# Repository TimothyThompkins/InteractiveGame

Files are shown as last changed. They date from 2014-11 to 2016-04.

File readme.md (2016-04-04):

## Description

This is a work in progress, but ultimately aspires to a space invaders-esque game which is played completely on an embedded touch controller and interfaced with a display device such as a computer, or Rasbery Pi.

### Current revision of the PCB:

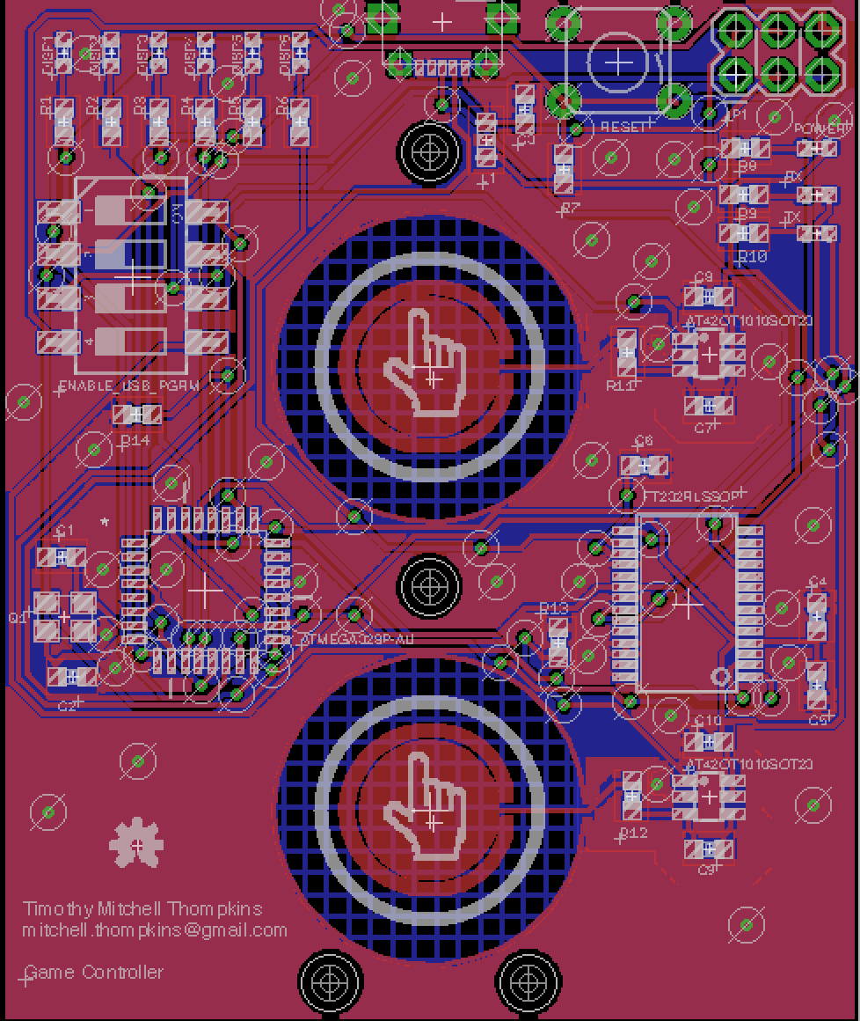
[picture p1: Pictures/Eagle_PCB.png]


### The unpopulated (left) and populated (right) boards:

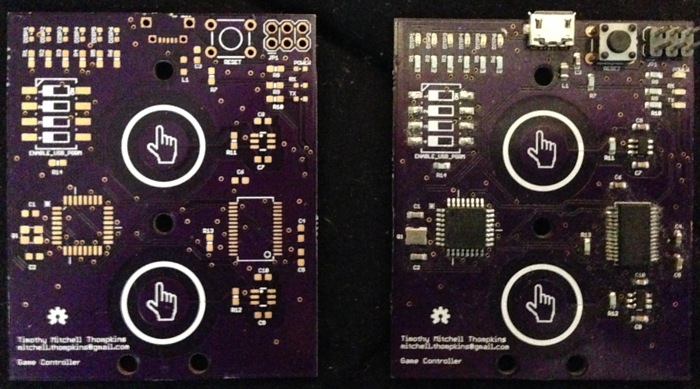
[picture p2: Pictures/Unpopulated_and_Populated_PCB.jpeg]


### Loading screen for the game, developed in python:

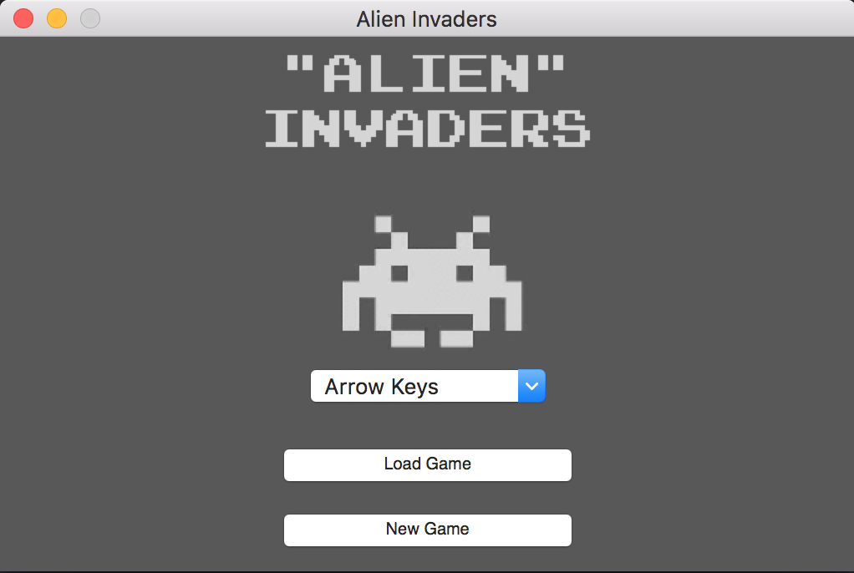
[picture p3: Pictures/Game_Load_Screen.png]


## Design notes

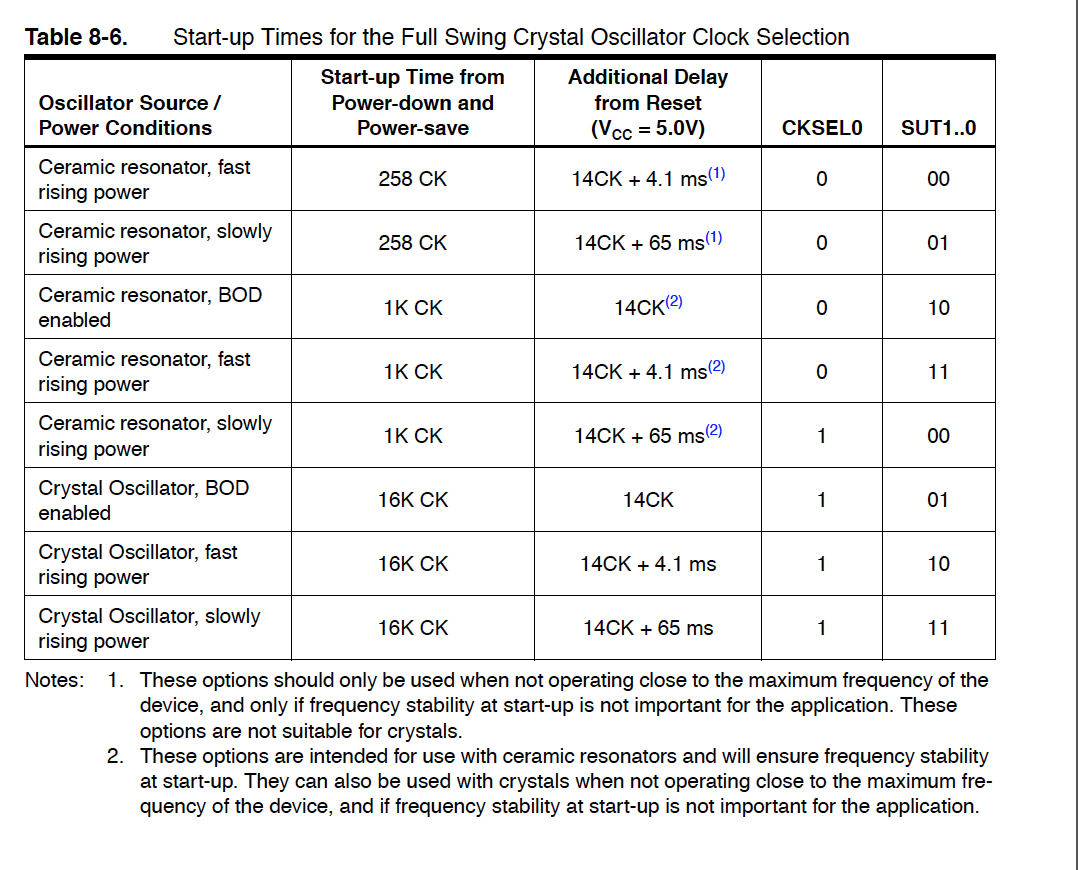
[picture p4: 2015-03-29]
Fuse Settings/High Fuse bit settings 2.png

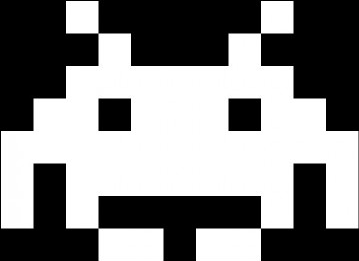
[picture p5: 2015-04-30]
Game/python/characters/alien.gif

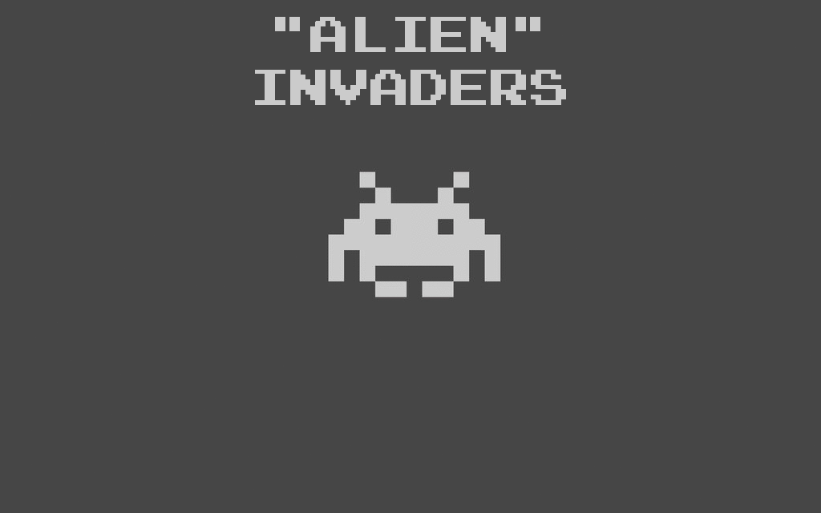
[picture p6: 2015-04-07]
Game/python/Space_Invaders_Background_Image.gif

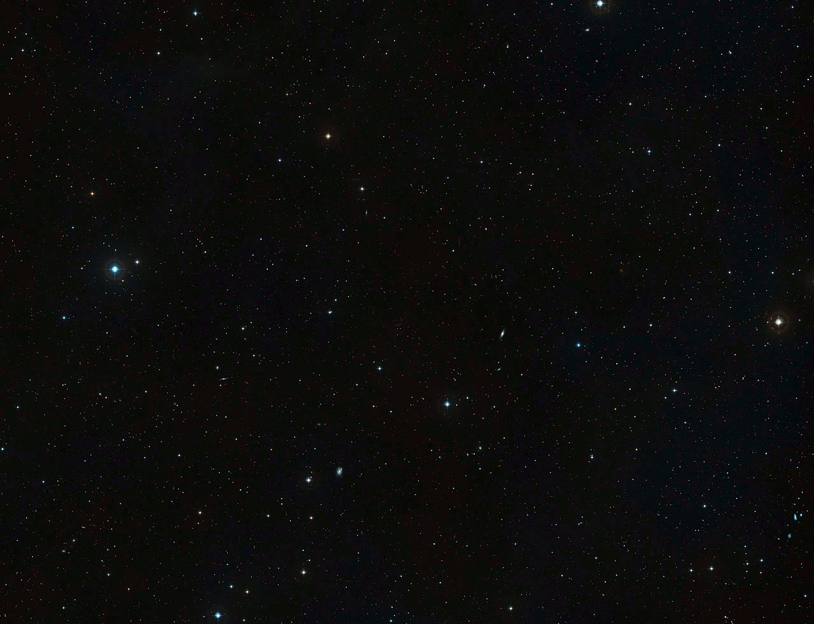
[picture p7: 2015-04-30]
Game/python/Game_Background.gif

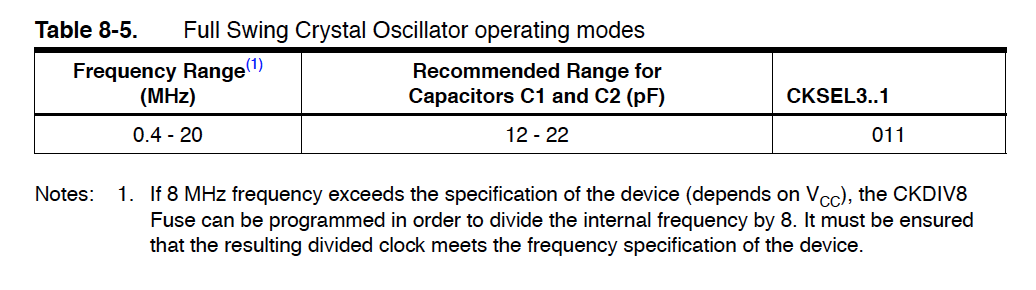
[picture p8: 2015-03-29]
Fuse Settings/High Fuse bit settings 1.png

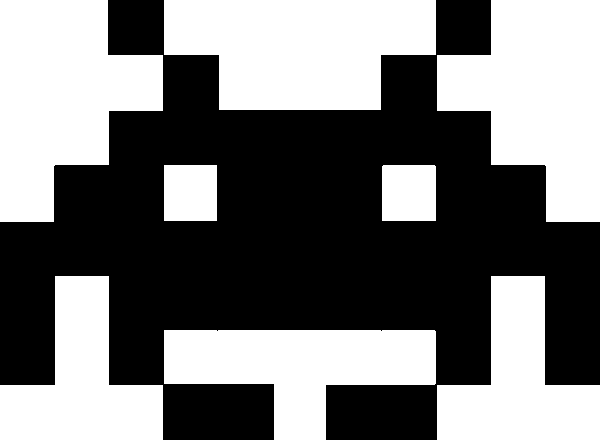
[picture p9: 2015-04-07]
Game/python/characters/temp.gif

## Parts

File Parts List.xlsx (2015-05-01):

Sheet: Parts List
 | Part | Package/Mounting Type | Size | Quantity | Notes | Order Link
Capacitors | 10 pF | SMD | 0603 | 2 | For Oscillator | http://www.digikey.com/product-detail/en/CL10C100JB8NCNC/1276-2154-1-ND/3890240
 | .01 μF | SMD | 0603 | 1 |  | http://www.digikey.com/product-detail/en/C0603C103K5RACTU/399-1091-1-ND/411366
 | .1 μF | SMD | 0603 | 14 |  | http://www.digikey.com/product-detail/en/CC0603KRX7R9BB104/311-1344-1-ND/2103128
 | 4.7 μF | SMD | 0603 | 2 |  | http://www.digikey.com/product-detail/en/CL10A475KA8NQNC/1276-1900-1-ND/3889986
Resistors | 150 Ω | SMD | 0603 | 9 |  | http://www.digikey.com/product-detail/en/MCT06030C1500FP500/MCT0603-150-CFCT-ND/2607884
 | 330 Ω | SMD | 0603 | 6 |  | http://www.digikey.com/product-detail/en/ESR03EZPJ331/RHM330DCT-ND/1762933
 | 10 kΩ | SMD | 0603 | 1 |  | http://www.digikey.com/product-detail/en/MCT06030C1002FP500/MCT0603-10.0K-CFCT-ND/2607933
LED | Red | SMD | 0603 | 6 | 1/8W 150 Ω Resistor | http://www.digikey.com/product-detail/en/APT1608SRCPRV/754-1122-1-ND/1747839
 | Yellow | SMD | 0603 | 1 | 1/8W 150 Ω Resistor | http://www.digikey.com/product-detail/en/APT1608SYCK/754-1124-1-ND/1747841
 | Green | SMD | 0603 | 2 | 1/8W 150 Ω Resistor | http://www.digikey.com/product-detail/en/APT1608CGCK/754-1116-1-ND/1747833
Bead | BK2125HS470-T | SMD | 0805 | 1 |  | http://www.digikey.com/product-detail/en/BK2125HS470-T/587-1911-1-ND/1465381
Chips | AT42QT1010SOT23 | SOT23-6 | N/A | 4 |  | http://www.digikey.com/product-detail/en/AT42QT1010-TSHR/AT42QT1010-TSHRCT-ND/2268871
 | ATMEGA328P | TQFP-32 | N/A | 1 |  | http://www.digikey.com/product-detail/en/ATMEGA328P-AU/ATMEGA328P-AU-ND/1832260
 | FT232RL | SSOP28DB | N/A | 1 |  | http://www.digikey.com/product-detail/en/FT232RL-REEL/768-1007-1-ND/1836402
Comms | FCI Micro-B USB | SMD/Through-Hole | N/A | 1 |  | http://www.digikey.com/product-detail/en/10118194-0001LF/609-4618-1-ND/2785382
Jumpers | 3x2 | Through-Hole | 2.54mm | 1 |  | http://www.digikey.com/product-detail/en/M20-9980346/952-2121-ND/3728085
Buttons | Momentary Push-Button | Through-Hole |  | 1 |  | N/A
Oscillator | 20 MHz Crystal Oscillator | SMD | 3.2mmx2.5mm | 1 | Assume Cstray = 4pF | http://www.digikey.com/product-detail/en/TSX-3225%2020.0000MF20G-AC3/SER3629CT-ND/1802880
 | MIC5205 | SOT23-5 |  | 1 |  | http://www.digikey.com/product-detail/en/MIC5205-3.3YM5%20TR/576-1259-1-ND/771886

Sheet: LED Calculations
Required Values of R given Vf, Vcc, and Current Max |  |  |  |  |  |  | How Changing R will affect I and P given Vf
Current Max | Vcc | Vf | R | P (V*I) | P (I2R) | Color | Vf (Given by Datasheet) | Choose R | I ((Vcc-Vf)/R) | P (I2R)
0.02 | 5 | 1.5 | 175 | 0.07 | 0.07 | Red | 1.85 | 150 | 0.021 | 0.06615
 |  | 1.6 | 170 | 0.068 | 0.068 | Yellow | 2 | 150 | 0.02 | 0.06
 |  | 1.7 | 165 | 0.066 | 0.066 | Green | 2.1 | 150 | 0.01933333333 | 0.05606666667
 |  | 1.8 | 160 | 0.064 | 0.064
 |  | 1.9 | 155 | 0.062 | 0.062 | NOTE: These LED's have a test current of 20mA and no series resistor is greater than 1/8 W (.125 W)
 |  | 2 | 150 | 0.06 | 0.06
 |  | 2.1 | 145 | 0.058 | 0.058
 |  | 2.2 | 140 | 0.056 | 0.056
 |  | 2.3 | 135 | 0.054 | 0.054
 |  | 2.4 | 130 | 0.052 | 0.052
 |  | 2.5 | 125 | 0.05 | 0.05
 |  | 2.6 | 120 | 0.048 | 0.048
 |  | 1.85 | 157.5 | 0.063 | 0.063

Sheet: Oscillator Calculations
Calculations for C1/C2
CL is given by datasheet and Cstray is assumed (usually between 2-5 pF) |  | Checking CL
CL (pF) | 9 | CL (pF) | 9
Cstray (pF) | 4 | C1 (pF) | 10
Calculated C1 and C2 (pF) | 10 | C2 (pF) | 10

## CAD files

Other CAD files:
Sketchup Files/Controller_Board.skp

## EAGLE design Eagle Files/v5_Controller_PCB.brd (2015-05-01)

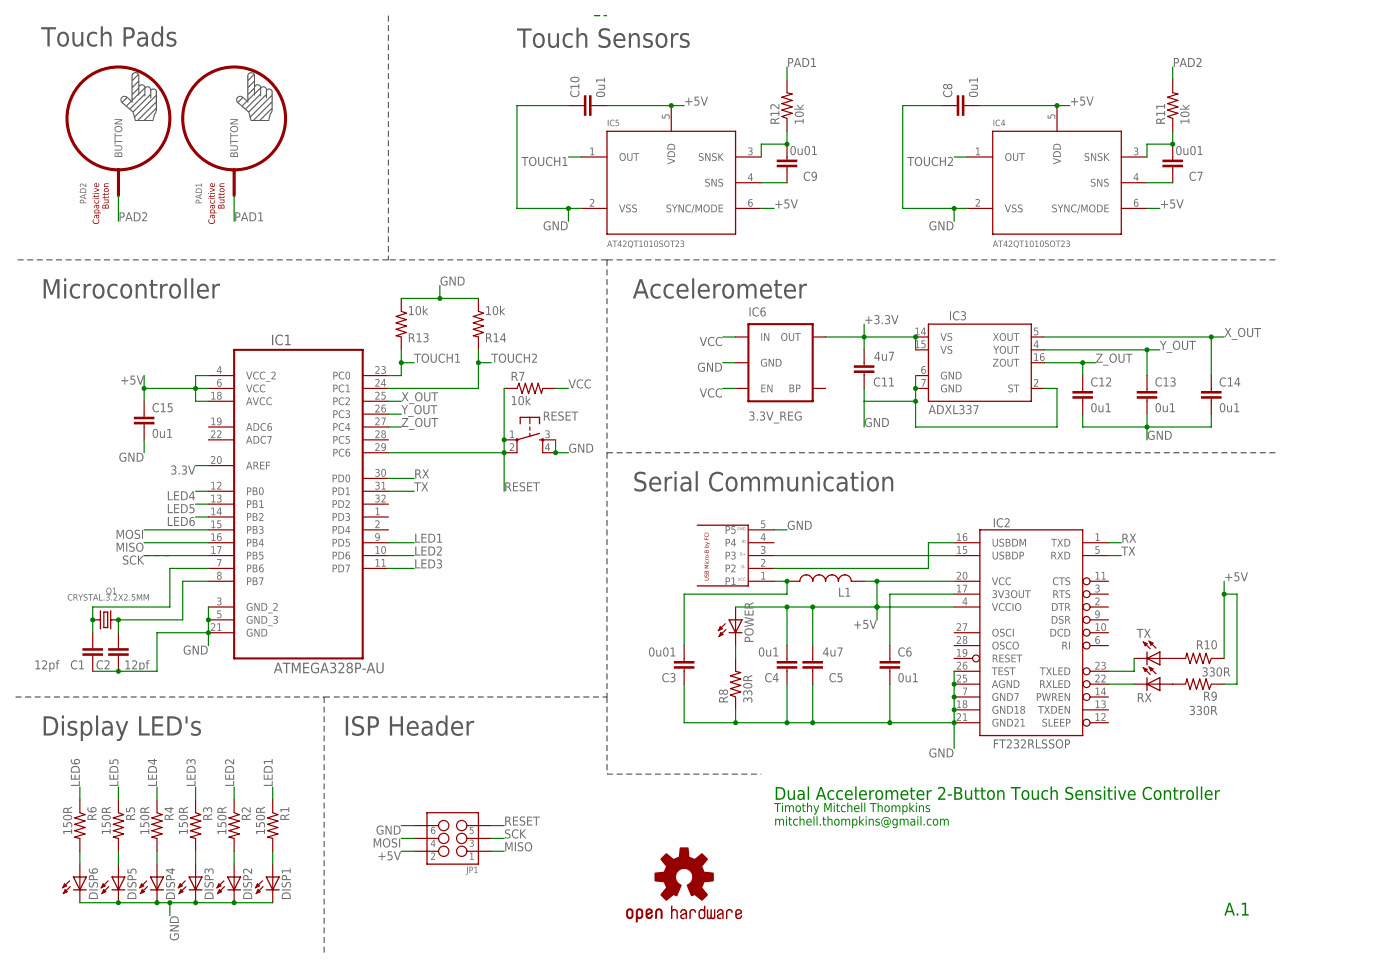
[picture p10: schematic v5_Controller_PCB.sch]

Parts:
BUTTON1: TOUCH_LOGO
C1, C2: 12pf; C0603
C3, C7, C9: 0u01; C0603
C4, C6, C8, C10, C12, C13, C14, C15: 0u1; C0603
C5, C11: 4u7; C0603
DISP1, DISP2, DISP3, DISP4, DISP5, DISP6: LEDCHIPLED_0603; CHIPLED_0603
IC1: ATMEGA328P-AU; QFP80P900X900X120-32N
IC2: FT232RLSSOP; SSOP28DB
IC3: ADXL337; LFCSP_LQ-16
IC4, IC5: AT42QT1010SOT23; SOT23-6
IC6: 3.3V_REG; SOT23-5
JP1: M03X2POGO_PINS; 2X3_POGO
L1: L-USL2012C; L2012C
LOGO2: OSHW-LOGOS; OSHW-LOGO-S
PAD1, PAD2: BUTTON_PASSIVE8MM; BUTTON_PASSIVE_8MM
POWER: LEDCHIPLED_0603; CHIPLED_0603
Q1: CRYSTAL.3.2X2.5MM; 3.2X2.5MM
R1, R2, R3, R4, R5, R6: 150R; 0603-RES
R7, R11, R12, R13, R14: 10k; 0603-RES
R8, R9, R10: 330R; 0603-RES
RESET: RESET; TACTILE_SWITCH_SMD
RX: LEDCHIPLED_0603; CHIPLED_0603
TX: LEDCHIPLED_0603; CHIPLED_0603
U$1: USB_MICRO_B_FCI; 10118194-0001LF
U$6: TOUCH_LOGO

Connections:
3.3V: IC1.20 (AREF)
+3.3V: C11.2, IC3.14 (VS), IC3.15 (VS), IC6.5 (OUT)
+5V: C4.2, C5.2, C8.2, C10.2, C15.1, IC1.4 (VCC_2), IC1.6 (VCC), IC1.18 (AVCC), IC2.4 (VCCIO), IC2.20 (VCC), IC4.5 (VDD), IC4.6 (SYNC/MODE), IC5.5 (VDD), IC5.6 (SYNC/MODE), JP1.P$2 (2), L1.2, POWER.A, R9.1, R10.1
GND: C1.1, C2.1, C3.1, C4.1, C5.1, C6.2, C8.1, C10.1, C11.1, C15.2, DISP1.C, DISP2.C, DISP3.C, DISP4.C, DISP5.C, DISP6.C, IC1.3 (GND_2), IC1.5 (GND_3), IC1.21 (GND), IC2.7 (GND7), IC2.18 (GND18), IC2.21 (GND21), IC2.25 (AGND), IC2.26 (TEST), IC3.2 (ST), IC3.6 (GND), IC3.7 (GND), IC4.2 (VSS), IC5.2 (VSS), IC6.2 (GND), JP1.P$6 (6), Q1.2 (GND), Q1.4 (GND), R8.1, R13.1, R14.1, RESET.3, RESET.4, U$1.5, U$1.GND@1 (GND), U$1.GND@2 (GND), U$1.GND@3 (GND), U$1.GND@4 (GND)
LED1: IC1.9 (PD5), R1.1
LED2: IC1.10 (PD6), R2.1
LED3: IC1.11 (PD7), R3.1
LED4: IC1.12 (PB0), R4.1
LED5: IC1.13 (PB1), R5.1
LED6: IC1.14 (PB2), R6.1
MISO: IC1.16 (PB4), JP1.P$1 (1)
MOSI: IC1.15 (PB3), JP1.P$4 (4)
unnamed: C9.2, IC5.3 (SNSK), R12.1
unnamed: C3.2, L1.1, U$1.1
unnamed: C2.2, IC1.8 (PB7), Q1.3
unnamed: C9.1, IC5.4 (SNS)
unnamed: POWER.C, R8.2
unnamed: C1.2, IC1.7 (PB6), Q1.1
unnamed: R10.2, TX.A
unnamed: C6.1, IC2.17 (3V3OUT)
unnamed: R9.2, RX.A
unnamed: IC2.16 (USBDM), U$1.2
unnamed: IC2.15 (USBDP), U$1.3
unnamed: IC2.23 (TXLED), TX.C
unnamed: IC2.22 (RXLED), RX.C
unnamed: C12.2, C13.2, C14.2
unnamed: C7.1, IC4.4 (SNS)
unnamed: C7.2, IC4.3 (SNSK), R11.1
unnamed: DISP1.A, R1.2
unnamed: DISP2.A, R2.2
unnamed: DISP3.A, R3.2
unnamed: DISP4.A, R4.2
unnamed: DISP5.A, R5.2
unnamed: DISP6.A, R6.2
PAD1: PAD1.P$1, R12.2
PAD2: PAD2.P$1, R11.2
RESET: IC1.29 (PC6), JP1.P$5 (5), R7.1, RESET.1, RESET.2
RX: IC1.30 (PD0), IC2.1 (TXD)
SCK: IC1.17 (PB5), JP1.P$3 (3)
TOUCH1: IC1.23 (PC0), IC5.1 (OUT), R13.2
TOUCH2: IC1.24 (PC1), IC4.1 (OUT), R14.2
TX: IC1.31 (PD1), IC2.5 (RXD)
VCC: IC6.1 (IN), IC6.3 (EN), R7.2
X_OUT: C14.1, IC1.25 (PC2), IC3.5 (XOUT)
Y_OUT: C13.1, IC1.26 (PC3), IC3.4 (YOUT)
Z_OUT: C12.1, IC1.27 (PC4), IC3.16 (ZOUT)

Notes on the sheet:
Timothy Mitchell Thompkins mitchell.thompkins@gmail.com
Dual Accelerometer 2-Button Touch Sensitive Controller
A.1
ISP Header
Touch Pads
Touch Sensors
Microcontroller
Serial Communication
Display LED's
Accelerometer

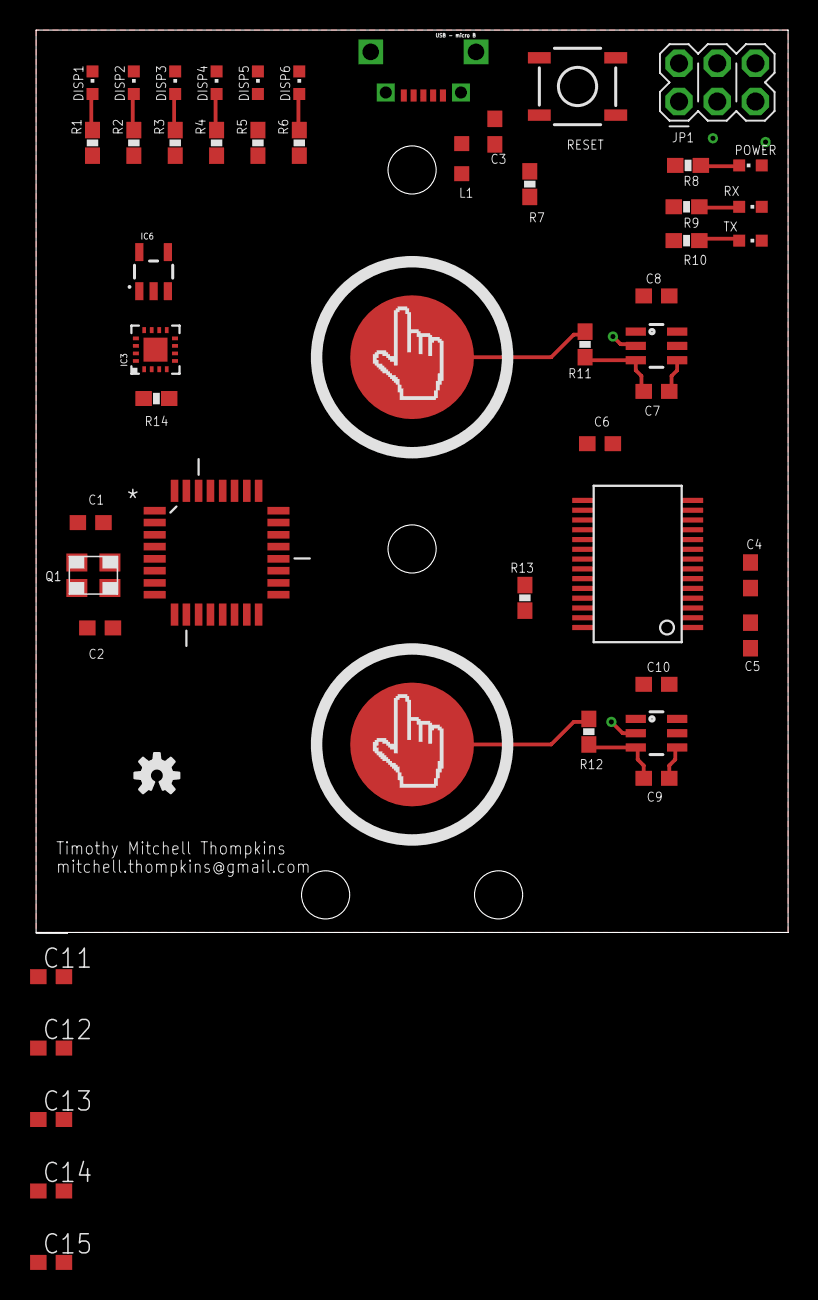
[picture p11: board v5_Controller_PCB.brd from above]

Board: 2 copper layers, 50.0 x 60.0 mm, 54 parts (0 on the bottom side), 45 nets.

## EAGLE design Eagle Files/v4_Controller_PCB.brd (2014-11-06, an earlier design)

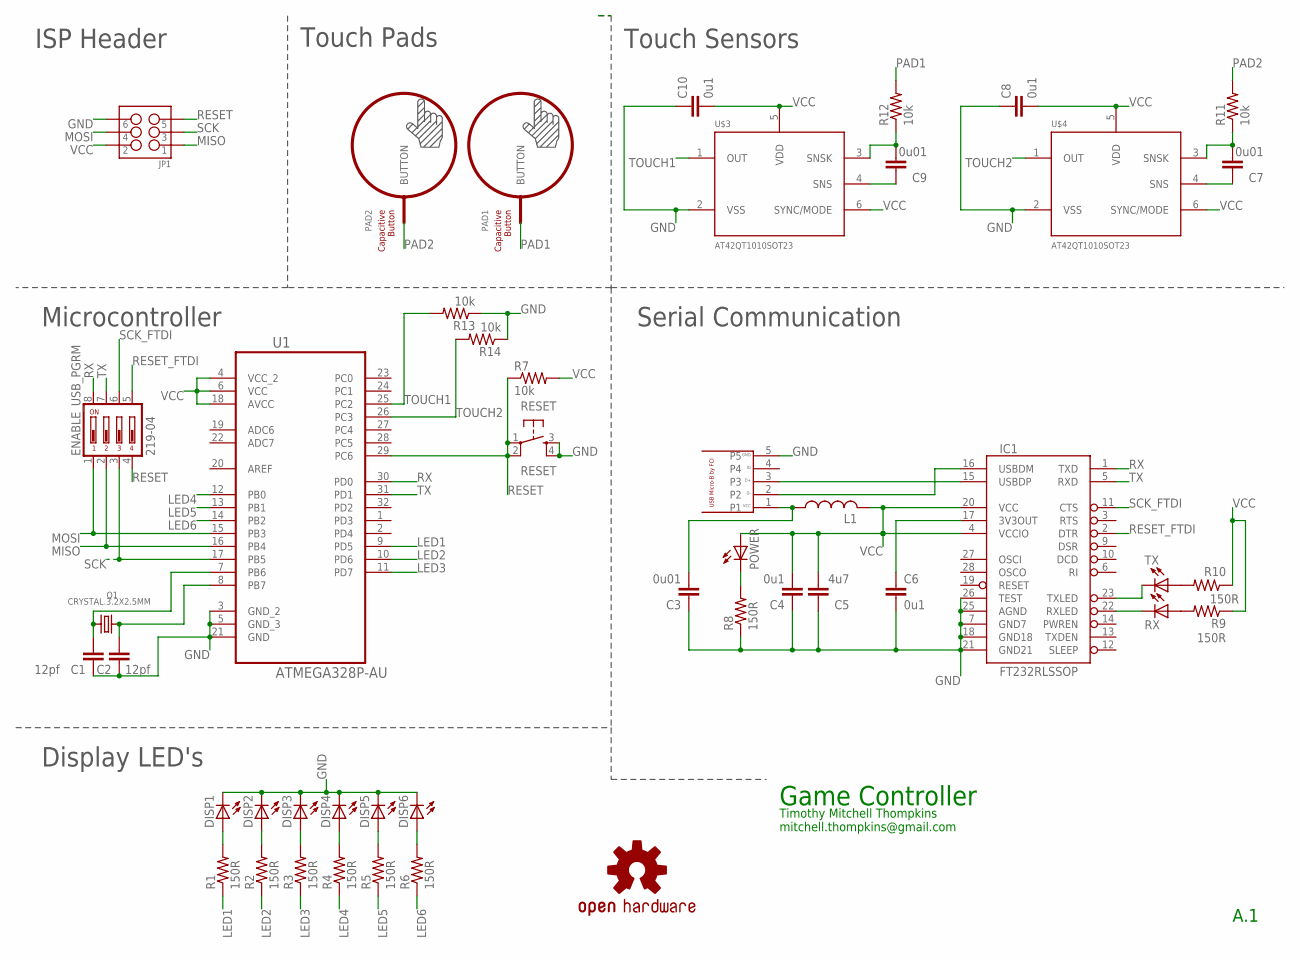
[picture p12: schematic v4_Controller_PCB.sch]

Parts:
BUTTON1: TOUCH_LOGO
C1, C2: 12pf; C0603
C3, C7, C9: 0u01; C0603
C4, C6, C8, C10: 0u1; C0603
C5: 4u7; C0603
DISP1, DISP2, DISP3, DISP4, DISP5, DISP6: LEDCHIPLED_0603; CHIPLED_0603
ENABLE_USB_PGRM: 219-04; CTS-219-04
IC1: FT232RLSSOP; SSOP28DB
JP1: M03X2POGO_PINS; 2X3_POGO
L1: L-USL2012C; L2012C
LOGO2: OSHW-LOGOS; OSHW-LOGO-S
PAD1, PAD2: BUTTON_PASSIVE8MM; BUTTON_PASSIVE_8MM
POWER: LEDCHIPLED_0603; CHIPLED_0603
Q1: CRYSTAL.3.2X2.5MM; 3.2X2.5MM
R1, R2, R3, R4, R5, R6, R8, R9, R10: 150R; 0603-RES
R7, R11, R12, R13, R14: 10k; 0603-RES
RESET: RESET; TACTILE-PTH
RX: LEDCHIPLED_0603; CHIPLED_0603
TX: LEDCHIPLED_0603; CHIPLED_0603
U1: ATMEGA328P-AU; QFP80P900X900X120-32N
U$1: USB_MICRO_B_FCI; 10118194-0001LF
U$3, U$4: AT42QT1010SOT23; SOT23-6
U$6: TOUCH_LOGO

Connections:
GND: C1.1, C2.1, C3.1, C4.1, C5.1, C6.2, C8.1, C10.1, DISP1.C, DISP2.C, DISP3.C, DISP4.C, DISP5.C, DISP6.C, IC1.7 (GND7), IC1.18 (GND18), IC1.21 (GND21), IC1.25 (AGND), IC1.26 (TEST), JP1.P$6 (6), Q1.2 (GND), Q1.4 (GND), R8.1, R13.1, R14.1, RESET.3, RESET.4, U1.3 (GND_2), U1.5 (GND_3), U1.21 (GND), U$1.5, U$1.GND@1 (GND), U$1.GND@2 (GND), U$1.GND@3 (GND), U$1.GND@4 (GND), U$3.2 (VSS), U$4.2 (VSS)
LED1: R1.1, U1.9 (PD5)
LED2: R2.1, U1.10 (PD6)
LED3: R3.1, U1.11 (PD7)
LED4: R4.1, U1.12 (PB0)
LED5: R5.1, U1.13 (PB1)
LED6: R6.1, U1.14 (PB2)
MISO: ENABLE_USB_PGRM.2, JP1.P$1 (1), U1.16 (PB4)
MOSI: ENABLE_USB_PGRM.1, JP1.P$4 (4), U1.15 (PB3)
unnamed: C9.2, R12.1, U$3.3 (SNSK)
unnamed: C3.2, L1.1, U$1.1
unnamed: C2.2, Q1.3, U1.8 (PB7)
unnamed: C9.1, U$3.4 (SNS)
unnamed: POWER.C, R8.2
unnamed: C1.2, Q1.1, U1.7 (PB6)
unnamed: R10.2, TX.A
unnamed: C6.1, IC1.17 (3V3OUT)
unnamed: R9.2, RX.A
unnamed: IC1.16 (USBDM), U$1.2
unnamed: IC1.15 (USBDP), U$1.3
unnamed: IC1.23 (TXLED), TX.C
unnamed: IC1.22 (RXLED), RX.C
unnamed: C7.1, U$4.4 (SNS)
unnamed: C7.2, R11.1, U$4.3 (SNSK)
unnamed: DISP1.A, R1.2
unnamed: DISP2.A, R2.2
unnamed: DISP3.A, R3.2
unnamed: DISP4.A, R4.2
unnamed: DISP5.A, R5.2
unnamed: DISP6.A, R6.2
PAD1: PAD1.P$1, R12.2
PAD2: PAD2.P$1, R11.2
RESET: ENABLE_USB_PGRM.4, JP1.P$5 (5), R7.1, RESET.1, RESET.2, U1.29 (PC6)
RESET_FTDI: ENABLE_USB_PGRM.5, IC1.2 (DTR)
RX: ENABLE_USB_PGRM.8, IC1.1 (TXD), U1.30 (PD0)
SCK: ENABLE_USB_PGRM.3, JP1.P$3 (3), U1.17 (PB5)
SCK_FTDI: ENABLE_USB_PGRM.6, IC1.11 (CTS)
TOUCH1: R13.2, U1.25 (PC2), U$3.1 (OUT)
TOUCH2: R14.2, U1.26 (PC3), U$4.1 (OUT)
TX: ENABLE_USB_PGRM.7, IC1.5 (RXD), U1.31 (PD1)
VCC: C4.2, C5.2, C8.2, C10.2, IC1.4 (VCCIO), IC1.20 (VCC), JP1.P$2 (2), L1.2, POWER.A, R7.2, R9.1, R10.1, U1.4 (VCC_2), U1.6 (VCC), U1.18 (AVCC), U$3.5 (VDD), U$3.6 (SYNC/MODE), U$4.5 (VDD), U$4.6 (SYNC/MODE)

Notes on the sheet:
Timothy Mitchell Thompkins mitchell.thompkins@gmail.com
Game Controller
A.1
ISP Header
Touch Pads
Touch Sensors
Microcontroller
Serial Communication
Display LED's

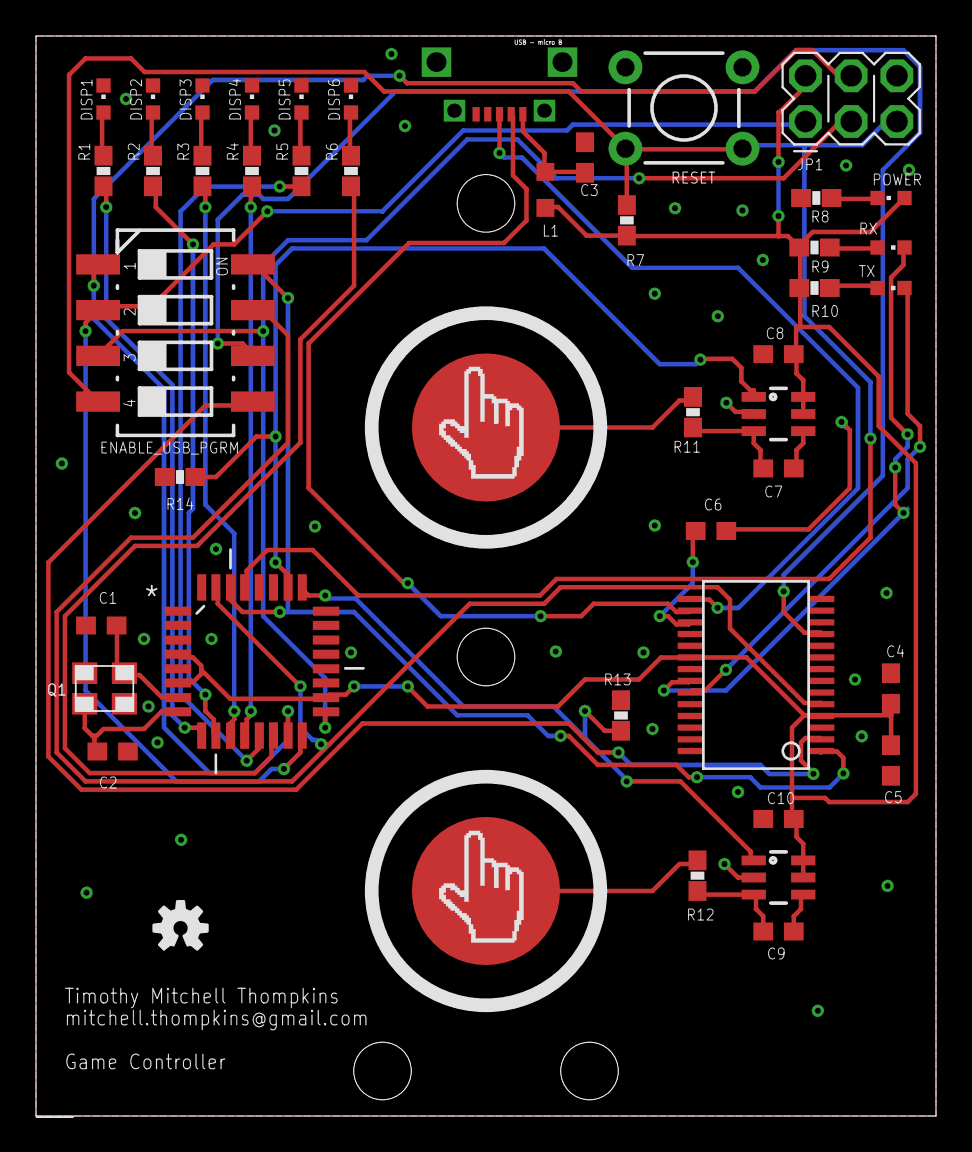
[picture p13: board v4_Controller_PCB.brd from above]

Board: 2 copper layers, 50.0 x 60.0 mm, 48 parts (0 on the bottom side), 41 nets.

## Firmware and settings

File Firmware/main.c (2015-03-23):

/*
* Hello_World.c
*
* Created: 9/28/2014 1:23:27 PM
*  Author: TimothyThompkins
*/

#define F_CPU 20000000UL // 20MHz

#include <avr/delay.h>
#include <avr/io.h>
#include <avr/interrupt.h>

#define 	UCSRA 	UCSR0A
#define 	UCSRB 	UCSR0B
#define 	UCSRC 	UCSR0C
#define 	UBRRH 	UBRR0H
#define 	UBRRL 	UBRR0L
#define 	UDRE 		UDRE0
#define 	UDR 		UDR0
#define 	RXC 		RXC0
#define 	TXEN		TXEN0
#define 	RXEN		RXEN0
#define 	RXCIE		RXCIE0

// Define baud rate
#define USART_BAUDRATE 9600
#define BAUD_PRESCALE (((F_CPU / (USART_BAUDRATE * 16UL))) - 1)

// Define baud rate 9600 is a safe speed as it is fast enough for most things we will use this speed
#define USART_BAUDRATE 9600

// Define the prescaler to use. This is based on the clock speed the AVR is running
#define BAUD_PRESCALE (((F_CPU / (USART_BAUDRATE * 16UL))) - 1)

void USART_Init(void){
	/*
	First set the BAUD rate, because this register is actually more than 8 bits
	we need to load the lower 8 bits and upper 8 bits independently from one another.
	We will load the lower 8 bits first and upper 8 bits after.
	Also the default frame format is 8 data bits, no parity and 1 stopbit (also known as 8n1))
	We will use this format so no change needed here
	*/
	UBRRL = BAUD_PRESCALE; // Load lower 8 bits
	UBRRH = (BAUD_PRESCALE >> 8); // Load upper 8 bits
	// Enable transmitter only
	// UCSRB = 1<<TXEN;
	UCSRB =(1<<RXEN0)|(1<<TXEN0);

}

void USART_SendByte(uint8_t data){

	// Wait until last byte has been transmitted
	while((UCSRA &(1<<UDRE)) == 0);

	// Transmit data
	UDR = data;
}

USART_ReceiveByte(){
	while ((UCSRA & (1 << RXC)) == 0);
	// Do nothing until data has been received and is ready to be read from UDR
	return(UDR); // return the byte
}

//volatile unsigned char value;
/* This variable is volatile so both main and RX interrupt can use it.
It could also be a uint8_t type */

/* Interrupt Service Routine for Receive Complete
NOTE: vector name changes with different AVRs see AVRStudio -
Help - AVR-Libc reference - Library Reference - <avr/interrupt.h>: Interrupts
for vector names other than USART_RXC_vect for ATmega32 */
/*
ISR(USART_RX_vect){

value = UDR;             //read UART register into value
PORTB = ~value;          // output inverted value on LEDs (0=on)
}

void USART_Init(void){
// Set baud rate
UBRRL = BAUD_PRESCALE;// Load lower 8-bits into the low byte of the UBRR register
UBRRH = (BAUD_PRESCALE >> 8);
Load upper 8-bits into the high byte of the UBRR register
Default frame format is 8 data bits, no parity, 1 stop bit
to change use UCSRC, see AVR datasheet

// Enable receiver and transmitter and receive complete interrupt
UCSRB = ((1<<TXEN)|(1<<RXEN) | (1<<RXCIE));
}


void USART_SendByte(uint8_t u8Data){

// Wait until last byte has been transmitted
while((UCSRA &(1<<UDRE)) == 0);

// Transmit data
UDR = u8Data;
}


// not being used but here for completeness
// Wait until a byte has been received and return received data
uint8_t USART_ReceiveByte(){
while((UCSRA &(1<<RXC)) == 0);
return UDR;
}
*/

int main(void)
{

	uint8_t data;
	USART_Init();  // Initialise USART
	//sei();         // enable all interrupts
	//value = 'A'; //0x41;

	//Pin I/O Definitions
	DDRB = 0b00000111;
	DDRC = 0b00000000;
	DDRD = 0b11100000;

	while(1)
	{
		//This is a hello world the LED's
		// for (uint8_t i = 5; i<=7; i++)
		// { //Start at 5 b/c the first LED is connected to PD5
		// PORTD ^= 1<<i;
		// _delay_ms(1000);//This is a 20ms delay
		// }
		//
		// for (uint8_t i = 0; i<=2; i++)
		// {
		// PORTB ^= 1<<i;
		// _delay_ms(1000);//This is a 20ms delay
		// }
		//
		// //USART_SendByte(value);  // send value
		// //data = USART_ReceiveByte();
		//
		// if (data == 'U')
		// {
		// 	//USART_SendByte('T');  // Send value
		// 	//_delay_ms(100);
		// }
		//
		// else
		// {
		// 	//USART_SendByte('N');  // Send value
		// 	//_delay_ms(100);
		// }

		if (PINC & (1<<PC2))
		{
			PORTD |= (1<<PD5);
		}
		else
		{
			PORTD &= ~(1<<PD5);
		}

		if (PINC & (1<<PC3))
		{
			PORTB |= (1<<PB2);
		}
		else
		{
			PORTB &= ~(1<<PB2);
		}
	}
}

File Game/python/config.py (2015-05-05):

import platform
import sys

class sys_config(object):

    def __init__(self):

        # These are what we need for each instance of game
        self.game_init = None
        self.new_game = None
        self.input_method = None
        self.serial_port = None
        self.baud_rate = None

        if sys.platform.startswith('win'):
            self.sys_platform = 'windows'

        # For Linux Platforms
        elif sys.platform.startswith('linux') or sys.platform.startswith('cygwin'):
            self.sys_platform = 'linux'

        # For OSX Platforms
        elif sys.platform.startswith('darwin'):
            self.sys_platform = 'OSX'

        else:
            self.sys_platform = None
            raise EnvironmentError('Unsupported platform')

        architecture = (platform.processor())

        # For Rasberry Pi (probably)
        if architecture == 'arm':

            # This window height is the pi resolution
            self.start_window_width = 480
            self.start_window_height = 320

            self.game_window_width = 480
            self.game_window_height = 320

            self.input_options = ['Tilt Sensor']

        # For PC
        else:
            self.start_window_width = 512
            self.start_window_height = 320

            self.game_window_width = 1024
            self.game_window_height = 640

            self.input_options = ['Arrow Keys','Web Cam','Tilt Sensor']

    # Get Data
    def get_sys_platform(self):
        return self.sys_platform

    def get_start_window_dim(self):
        return (self.start_window_width, self.start_window_height)

    def get_game_window_dim(self):
        return (self.game_window_width, self.game_window_height)

    def get_sys_input_options(self):
        return self.input_options

    def get_game_init(self):
        return self.game_init

    def get_new_game(self):
        return self.new_game

    def get_input_method(self):
        return self.input_method

    def get_serial_port(self):
        return self.serial_port

    def get_baud_rate(self):
        return self.baud_rate

    # Set Data
    def set_game_init(self, game_init):
        self.game_init = game_init

    def set_new_game(self, new_game):
        self.new_game = new_game

    def set_input_method(self, input_method):
        self.input_method = input_method

    def set_serial_port(self, serial_port):
        self.serial_port = serial_port

    def set_baud_rate(self, baud_rate):
        self.baud_rate = baud_rate


    def print_data(self):
        print (self.new_game, self.input_method, self.serial_port, self.baud_rate)

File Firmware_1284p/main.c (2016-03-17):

/*
* main.c
*
* Created: 2015/03/29
*  Author: Timothy Thompkins
*/

#define FOSC 20000000UL
#define USART_BAUDRATE 9600
#define BAUD_PRESCALE (((( FOSC / 16) + ( USART_BAUDRATE / 2) ) / ( USART_BAUDRATE )) - 1)

#include <util/delay.h>
#include <avr/io.h>

#include "serial.h"

/*
 Function Prototypes in Main:
*/
// TMT This is a comment to test make
ISR(USART_RXC_vect);
void pinConfig(void);
int main(void);

/* Test Varialbes */
extern volatile uint8_t receivedByte;
uint8_t running_count = 0;
uint8_t tst_count = 0;
uint8_t tst_count_2 = 0;
uint8_t tst_value = 0;
uint8_t u8test = 0;

// Declare Buffers
u8buf_Rx RxBuffer;
u8buf_Tx TxBuffer;

// RX Complete interrupt service routine //USART_RX_vect on 328P
// ISR is triggered when RX is complete
ISR(USART0_RX_vect)
{
		uint8_t u8temp;
		u8temp = UDR0;

		RxBufferWrite(&RxBuffer, u8temp); // Writes data to buffer
}

void pinConfig(void) {
	DDRB = 0b00001000;
	DDRC = 0b00000000;
	DDRD = 0b11100000;
}

int main(void)
{

		// uint8_t test_comms = 'z';
		// uint8_t setupState = 1;
		// uint8_t *setupData; // Pointer to hold setup data

		USART_Init(BAUD_PRESCALE);  // Initialise USART
		pinConfig(); // Initialize Pin Configuration

		// Main loop
		while(1)
		{

			// while(setupState) // Wait in this while loop while waiting for user conig
			// {
			// 	setupData = getSetup();
			// 	if ((*setupData + 0) == 1) // 3rd Element of pointer is init flag. If true break while loop and start.
			// 	{
			// 		setupState = 0;
			// 	}
			// }

			// PORTB |= (1<<PB3);
			// _delay_ms(1000);
			// PORTB &= ~(1<<PB3);

			if (PINC & (1<<PC0)) {
				PORTB |= (1<<PB3);

				// u8temp = running_count == 0? 't' : 'm';
					if (tst_count < 1)
					{
						for(uint8_t i = RxBuffer.index; i > 0; i--)
						{
						u8test = RxBuffer.buffer[i-1];
						TxBufferWrite(&TxBuffer, u8test);
						tst_count++;
						}
					}
					running_count++;
			}
			else
			{
				PORTB &= ~(1<<PB3);
				tst_count = 0;
			}

			if (PINC & (1<<PC7))
			{
					if(tst_count_2 < 1){
					PORTB |= (1<<PB3);
					// uint8_t test_data = 8;
					// USART_Test_Transmit(tst_value);
					USART_Transmit(&TxBuffer);
					RxBufferReset(&RxBuffer);
					// USART_Transmit(&RxBuffer);
					tst_count_2++;
				}

			}
			else {
				PORTB &= ~(1<<PB3);
				tst_count_2 = 0;
			}

			// if (receivedByte == 'k') {
			// 	PORTB |= (1<<PB3);
			// }
			// else {
			// 	PORTB &= ~(1<<PB3);
			// }

		}
}

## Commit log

2015-03-23 Going Home
    [Parts List.xlsx]
2015-03-23 Changed LED Test Pins
2015-04-07 Trying to get event binding working
    [config.py, main.py, windows.py]
2015-04-27 Start Error Handling. Argument Passing working
    [config.py, main.py, serial_comms.py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]
2015-04-27 Error Message working. Minus Image
    [config.py, main.py, windows.py]
2015-04-28 Got error message correct and window cleaned up.
    [windows.py]
2015-04-30 Gearing up to start comms. Linux verison buggy
    [config.py, main.py, serial_comms.py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]
2015-04-30 Fixed some dumb linux vs OSX bull
    [windows.py]
2015-05-01 Overhauling Circuit Diagram
    [Parts List.xlsx, v5_Controller_PCB.brd, v5_Controller_PCB.sch]

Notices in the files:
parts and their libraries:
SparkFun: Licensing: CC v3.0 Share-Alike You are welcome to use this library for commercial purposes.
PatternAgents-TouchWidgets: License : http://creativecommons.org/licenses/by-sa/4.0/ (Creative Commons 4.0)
